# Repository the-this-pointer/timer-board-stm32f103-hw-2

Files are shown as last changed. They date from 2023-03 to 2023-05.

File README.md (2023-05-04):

# Timer Board Design Files

This repository contains the KiCAD PCB design files for my <a href="https://github.com/the-this-pointer/timer-board-stm32f103" target="_blank">universal timer board</a>.

There are two PCBs for main board and a panel board to let user set the configuration.

Caution: The PCBs not tested yet!

Main board:
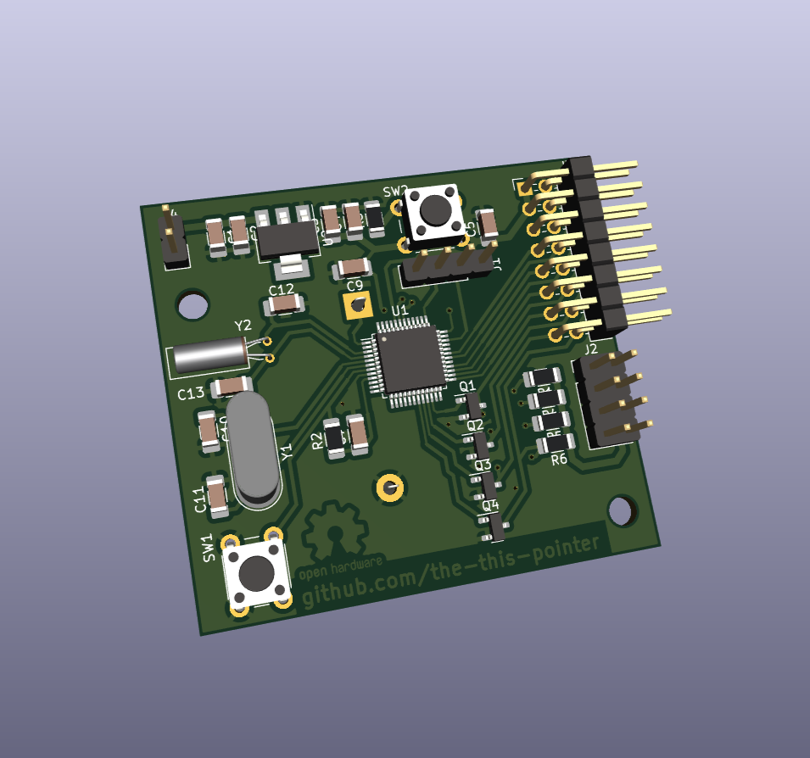
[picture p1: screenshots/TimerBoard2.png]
Main Board


Panel board:
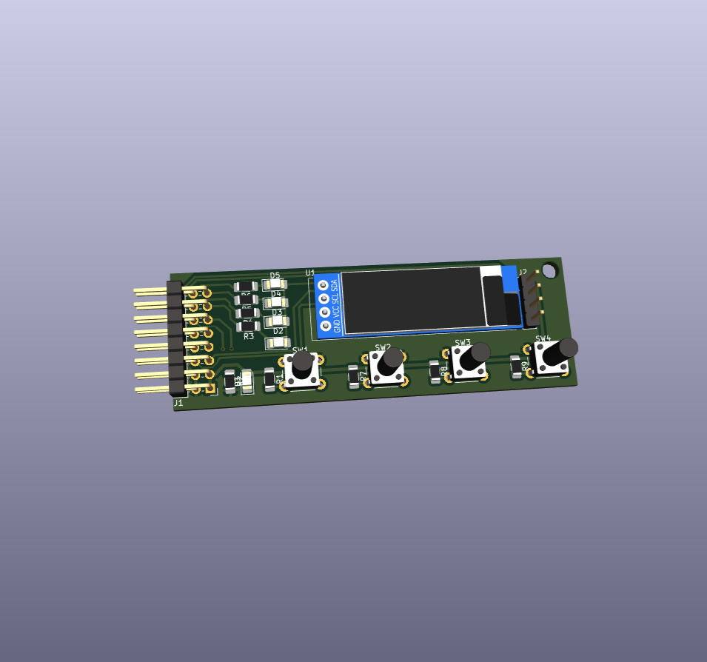
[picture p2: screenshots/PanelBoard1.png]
Panel Board


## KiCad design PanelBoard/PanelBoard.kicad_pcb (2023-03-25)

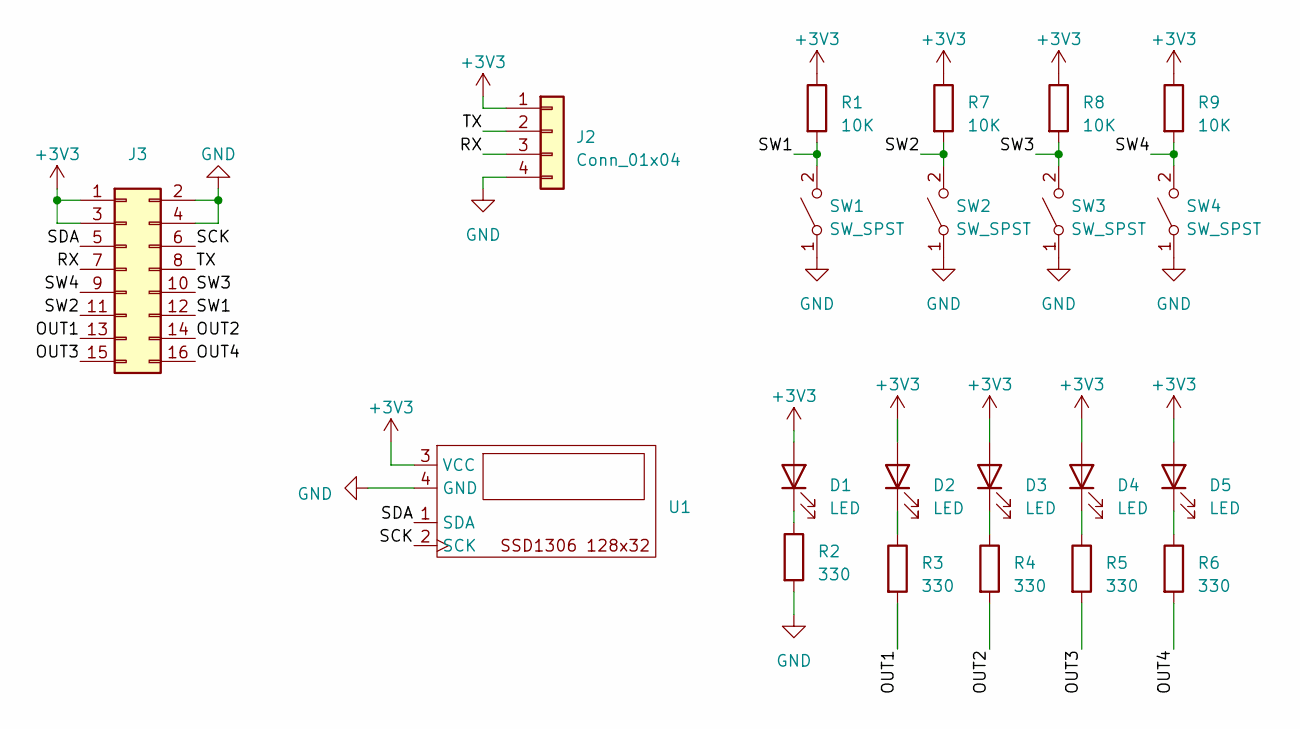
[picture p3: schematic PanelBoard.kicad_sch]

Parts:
D1, D2, D3, D4, D5: LED; LED_1206_3216Metric_Pad1.42x1.75mm_HandSolder
J2: Conn_01x04; PinHeader_1x04_P2.54mm_Vertical
J3: Conn_02x08_Odd_Even; PinHeader_2x08_P2.54mm_Horizontal
R1, R7, R8, R9: 10K; R_1206_3216Metric_Pad1.30x1.75mm_HandSolder
R2, R3, R4, R5, R6: 330; R_1206_3216Metric_Pad1.30x1.75mm_HandSolder
SW1, SW2, SW3, SW4: SW_SPST; SW_PUSH_6mm_H13mm
U1: OLED_SSD1306_128x32_0.91

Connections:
+3V3: D1.2 (A), D2.2 (A), D3.2 (A), D4.2 (A), D5.2 (A), J2.1, R1.1, R7.1, R8.1, R9.1, U1.3 (VCC); also elsewhere on the board
/OUT1: R3.2; also elsewhere on the board
/OUT2: R4.2; also elsewhere on the board
/OUT3: R5.2; also elsewhere on the board
/OUT4: R6.2; also elsewhere on the board
/RX: J2.3; also elsewhere on the board
/SCK: U1.2 (SCK); also elsewhere on the board
/SDA: U1.1 (SDA); also elsewhere on the board
/SW1: R1.2, SW1.2 (B); also elsewhere on the board
/SW2: R7.2, SW2.2 (B); also elsewhere on the board
/SW3: R8.2, SW3.2 (B); also elsewhere on the board
/SW4: R9.2, SW4.2 (B); also elsewhere on the board
/TX: J2.2; also elsewhere on the board
GND: J2.4, R2.2, SW1.1 (A), SW2.1 (A), SW3.1 (A), SW4.1 (A), U1.4 (GND); also elsewhere on the board
unnamed: D1.1 (K), R2.1
unnamed: D2.1 (K), R3.1
unnamed: D3.1 (K), R4.1
unnamed: D4.1 (K), R5.1
unnamed: D5.1 (K), R6.1

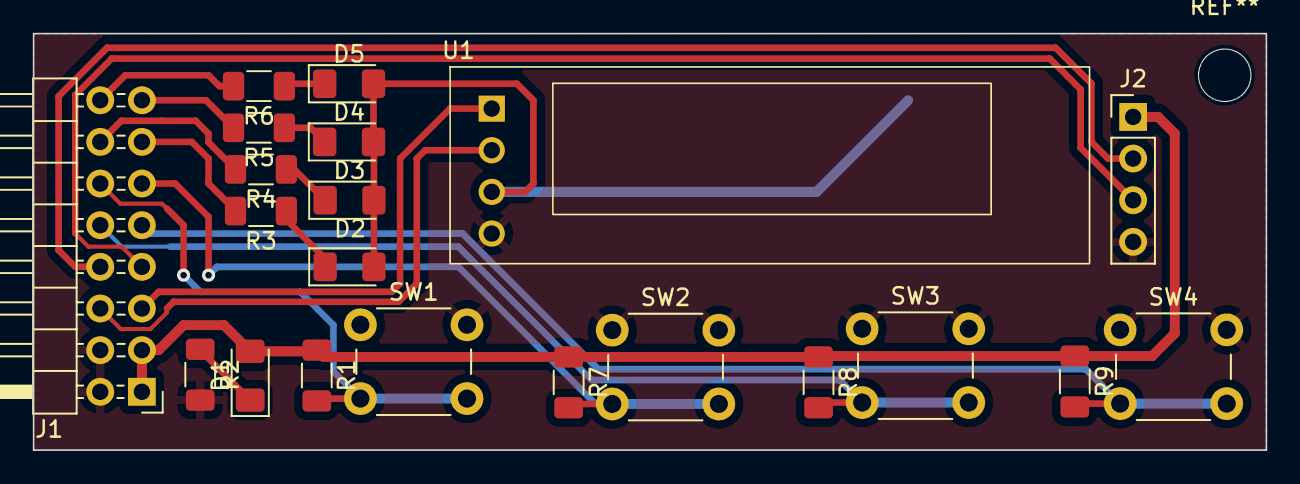
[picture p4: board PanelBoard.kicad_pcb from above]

Board: 2 copper layers, 75.2 x 25.4 mm, 21 parts (0 on the bottom side), 19 nets.

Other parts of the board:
J1: Conn_02x08_Odd_Even; PinHeader_2x08_P2.54mm_Horizontal

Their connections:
+3V3: J1.1, J1.3; also elsewhere on the board
/OUT1: J1.13; also elsewhere on the board
/OUT2: J1.14; also elsewhere on the board
/OUT3: J1.15; also elsewhere on the board
/OUT4: J1.16; also elsewhere on the board
/RX: J1.7; also elsewhere on the board
/SCK: J1.6; also elsewhere on the board
/SDA: J1.5; also elsewhere on the board
/SW1: J1.12; also elsewhere on the board
/SW2: J1.11; also elsewhere on the board
/SW3: J1.10; also elsewhere on the board
/SW4: J1.9; also elsewhere on the board
/TX: J1.8; also elsewhere on the board
GND: J1.2, J1.4; also elsewhere on the board

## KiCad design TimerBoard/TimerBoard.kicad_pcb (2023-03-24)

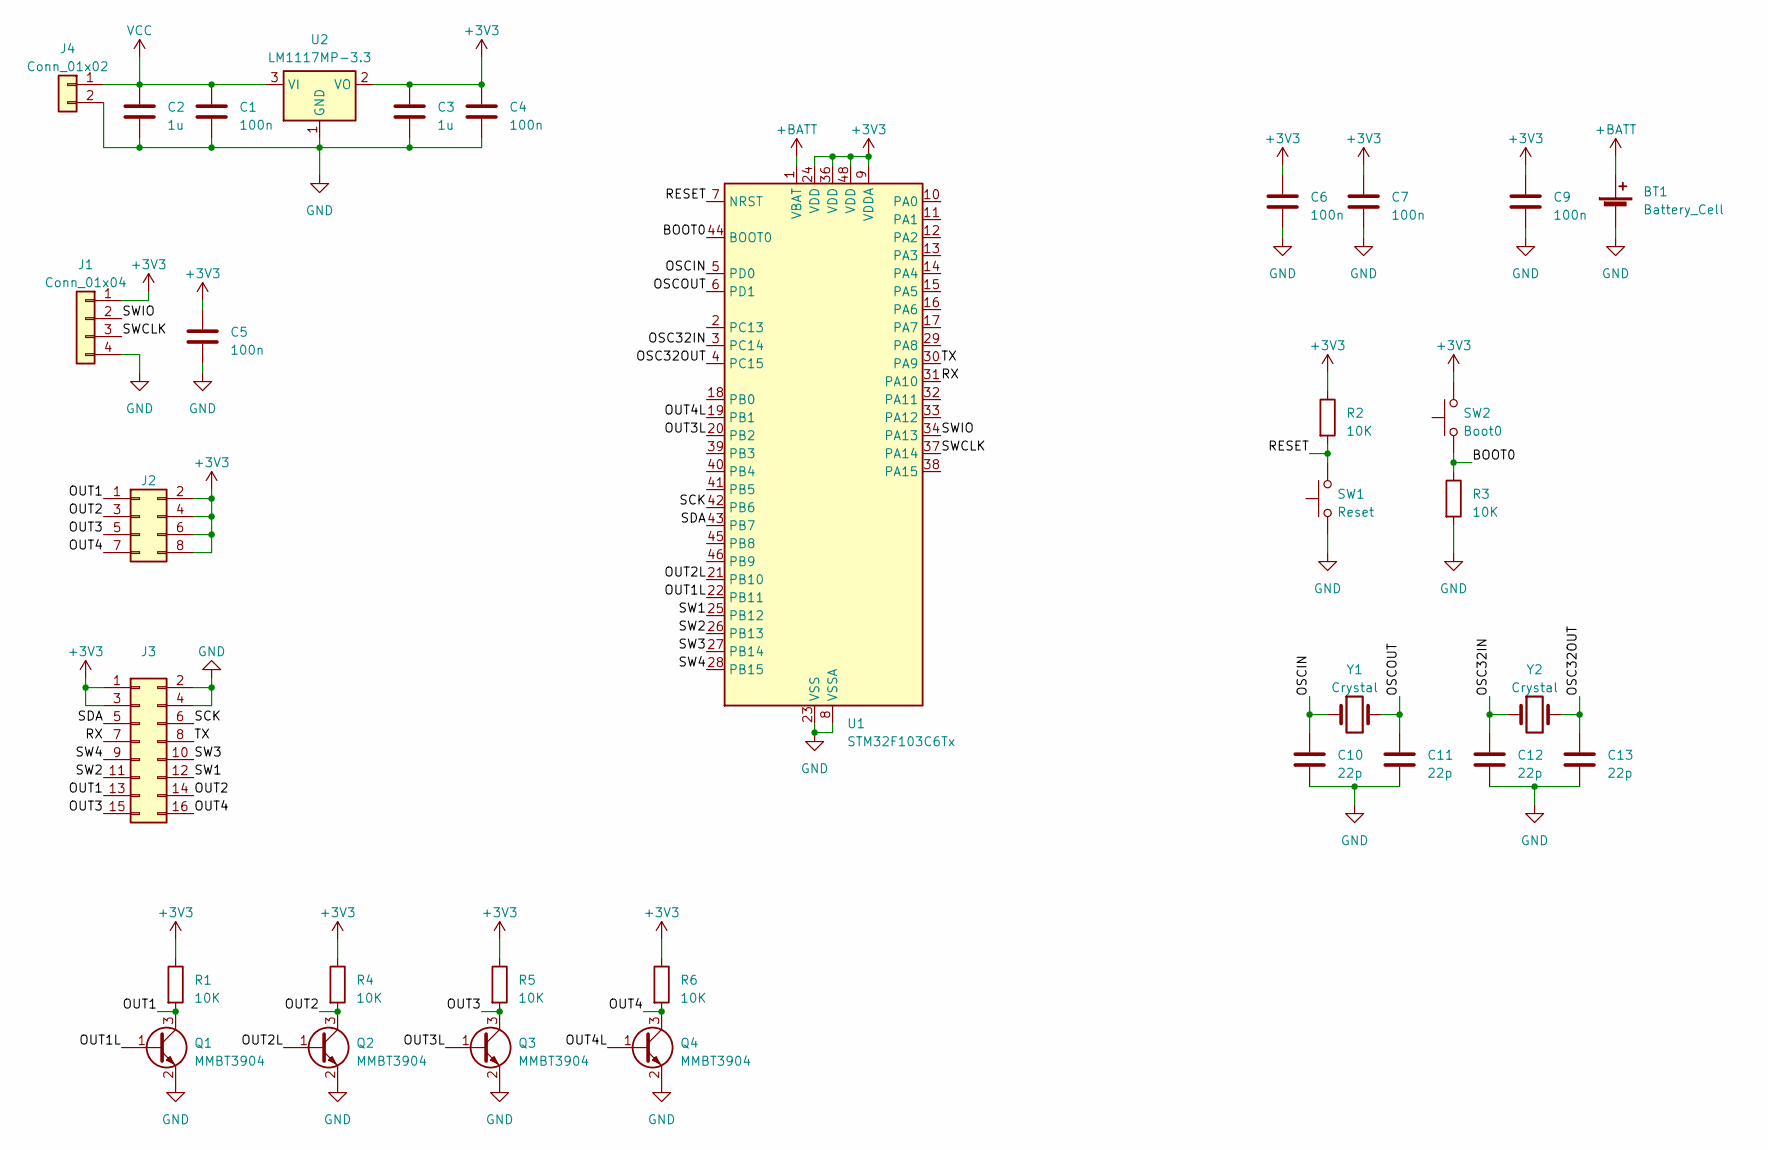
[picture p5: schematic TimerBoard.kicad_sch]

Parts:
BT1: Battery_Cell; BatteryHolder_Keystone_104_1x23mm
C1, C4, C5, C6, C7, C9: 100n; C_1206_3216Metric_Pad1.33x1.80mm_HandSolder
C2, C3: 1u; C_1206_3216Metric_Pad1.33x1.80mm_HandSolder
C10, C11, C12, C13: 22p; C_1206_3216Metric_Pad1.33x1.80mm_HandSolder
J1: Conn_01x04; PinHeader_1x04_P2.54mm_Vertical
J2: Conn_02x04_Odd_Even; PinHeader_2x04_P2.54mm_Vertical
J3: Conn_02x08_Odd_Even; PinHeader_2x08_P2.54mm_Horizontal
J4: Conn_01x02; PinHeader_1x02_P2.54mm_Vertical
Q1, Q2, Q3, Q4: MMBT3904; SOT-23
R1, R2, R3, R4, R5, R6: 10K; R_1206_3216Metric_Pad1.30x1.75mm_HandSolder
SW1: Reset; SW_PUSH_6mm
SW2: Boot0; SW_PUSH_6mm
U1: STM32F103C6Tx; LQFP-48_7x7mm_P0.5mm
U2: LM1117MP-3.3; SOT-223-3_TabPin2
Y1: Crystal; Crystal_HC49-U_Vertical
Y2: Crystal; Crystal_C38-LF_D3.0mm_L8.0mm_Horizontal

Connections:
+3V3: C3.1, C4.1, C5.1, C6.1, C7.1, C9.1, J1.1, J2.2, J2.4, J2.6, J2.8, J3.1, J3.3, R1.1, R2.1, R4.1, R5.1, R6.1, SW2.2, U1.9 (VDDA), U1.24 (VDD), U1.36 (VDD), U1.48 (VDD), U2.2 (VO)
+BATT: BT1.1 (+), U1.1 (VBAT)
/BOOT0: R3.1, SW2.1, U1.44 (BOOT0)
/OSC32IN: C12.1, U1.3 (PC14), Y2.1
/OSC32OUT: C13.1, U1.4 (PC15), Y2.2
/OSCIN: C10.1, U1.5 (PD0), Y1.1
/OSCOUT: C11.1, U1.6 (PD1), Y1.2
/OUT1: J2.1, J3.13, Q1.3 (C), R1.2
/OUT1L: Q1.1 (B), U1.22 (PB11)
/OUT2: J2.3, J3.14, Q2.3 (C), R4.2
/OUT2L: Q2.1 (B), U1.21 (PB10)
/OUT3: J2.5, J3.15, Q3.3 (C), R5.2
/OUT3L: Q3.1 (B), U1.20 (PB2)
/OUT4: J2.7, J3.16, Q4.3 (C), R6.2
/OUT4L: Q4.1 (B), U1.19 (PB1)
/RESET: R2.2, SW1.2, U1.7 (NRST)
/RX: J3.7, U1.31 (PA10)
/SCK: J3.6, U1.42 (PB6)
/SDA: J3.5, U1.43 (PB7)
/SW1: J3.12, U1.25 (PB12)
/SW2: J3.11, U1.26 (PB13)
/SW3: J3.10, U1.27 (PB14)
/SW4: J3.9, U1.28 (PB15)
/SWCLK: J1.3, U1.37 (PA14)
/SWIO: J1.2, U1.34 (PA13)
/TX: J3.8, U1.30 (PA9)
GND: BT1.2 (-), C1.2, C2.2, C3.2, C4.2, C5.2, C6.2, C7.2, C9.2, C10.2, C11.2, C12.2, C13.2, J1.4, J3.2, J3.4, J4.2, Q1.2 (E), Q2.2 (E), Q3.2 (E), Q4.2 (E), R3.2, SW1.1, U1.8 (VSSA), U1.23 (VSS), U1.35 (VSS), U1.47 (VSS), U2.1 (GND)
VCC: C1.1, C2.1, J4.1, U2.3 (VI)

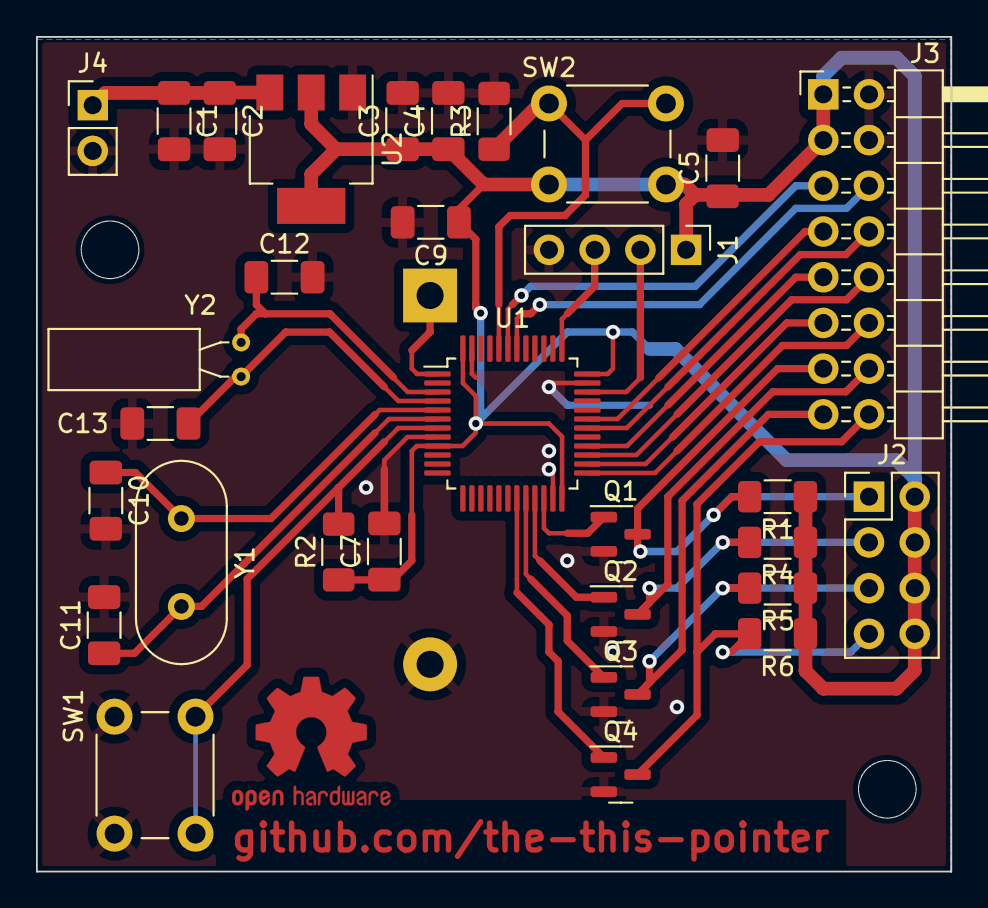
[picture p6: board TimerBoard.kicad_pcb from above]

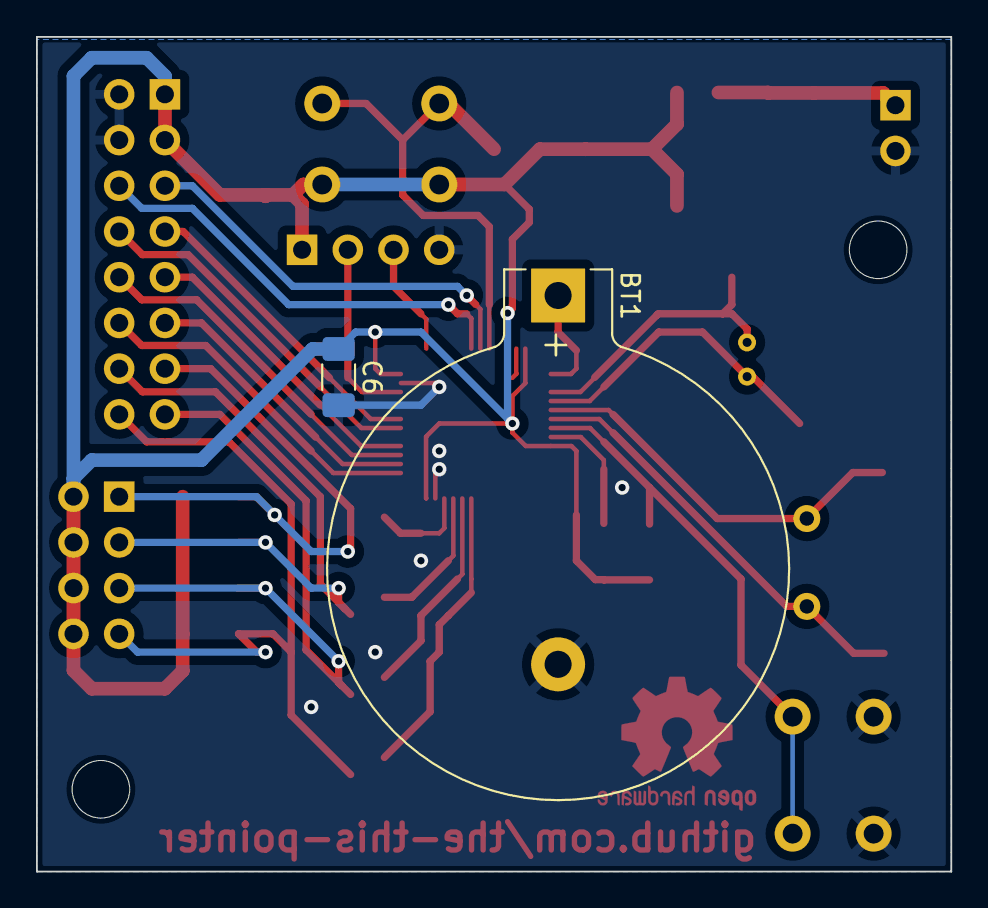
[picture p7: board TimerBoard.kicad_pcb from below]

Board: 2 copper layers, 50.8 x 46.4 mm, 33 parts (2 on the bottom side), 28 nets.

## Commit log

2023-03-23 panel pcb project created
    [PanelBoard.kicad_pcb, PanelBoard.kicad_sch]
2023-03-24 timer board added
    [TimerBoard.kicad_pcb, TimerBoard.kicad_sch]
2023-03-25 panel board pcb designed
    [PanelBoard.kicad_pcb, PanelBoard.kicad_sch]
